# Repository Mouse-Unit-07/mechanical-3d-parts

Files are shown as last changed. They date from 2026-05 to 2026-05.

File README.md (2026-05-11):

# Mechanical 3D Parts

- Mechanical documentation and references for 3D printed parts on the micromouse
- Mechanical calculations and part selections are too closely related to electrical hardware design- this repo will include just 3D modeling related notes
- Includes:
  - Reference links to 3D modeling guides
  - Notes for 3D modeled parts
  - 3D model files for motherboard mounts, wheels, etc

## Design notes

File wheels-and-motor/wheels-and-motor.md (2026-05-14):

# Wheels and Motor Design Explanation

- Notes regarding wheels and related design choices

## Index

- [4 Wheel Drive](#4-wheel-drive)
- [Gears](#gears)
- [Wheel Bearing Spacers](#wheel-bearing-spacers)- [Mechanical Micromouse Specs](#mechanical-micromouse-specs)

## 4 Wheel Drive

- Decimus 4
  - https://micromouseonline.com/2012/05/16/shapeways-motor-mounts-arrive/
  - https://micromouseonline.com/2012/05/24/printed-wheels-complete-decimus-mechanicals/
  - The key is to use ball bearings, spacers, and a screw for a shaft for the wheels to rotate
  - M3 screws and 3mm diameter ball bearings are used for Mouse Unit 07
- Designing gears
  - The key is to design wheels w/ gears on them
  - More details in mechanical design guide

## Gears

- Fusion 360 guide to making gears: https://www.youtube.com/watch?v=B8A_11o7QZ0
- To minimize friction, below settings were used w/ the spur gear generation tool:

```
given 32mm wheels, and target gear ratio of 13:44 pinion to wheel gear:

wheel gear:
- teeth: 44
- module: 0.65
- pressure angle: 20 degrees
- backlash: 0.15
- root fillet radius: 0.38mm
- gear thickness: 3mm
- calculated pitch diameter of 28.6mm (0.65 * 44 = 28.6mm)
- calculated outer diameter of 0.65(44 + 2) = 29.9mm

pinion:
- teeth: 13
- module: 0.65
- pressure angle: 20 degrees
- backlash: 0.15
- root fillet radius: 0.38mm
- gear thickness: 3mm
- calculated pitch diameter of 28.6mm (0.65 * 13 = 8.5mm)
- calculated outer diameter of 0.65(13 + 2) = 9.75mm

```

- Gear train orientation
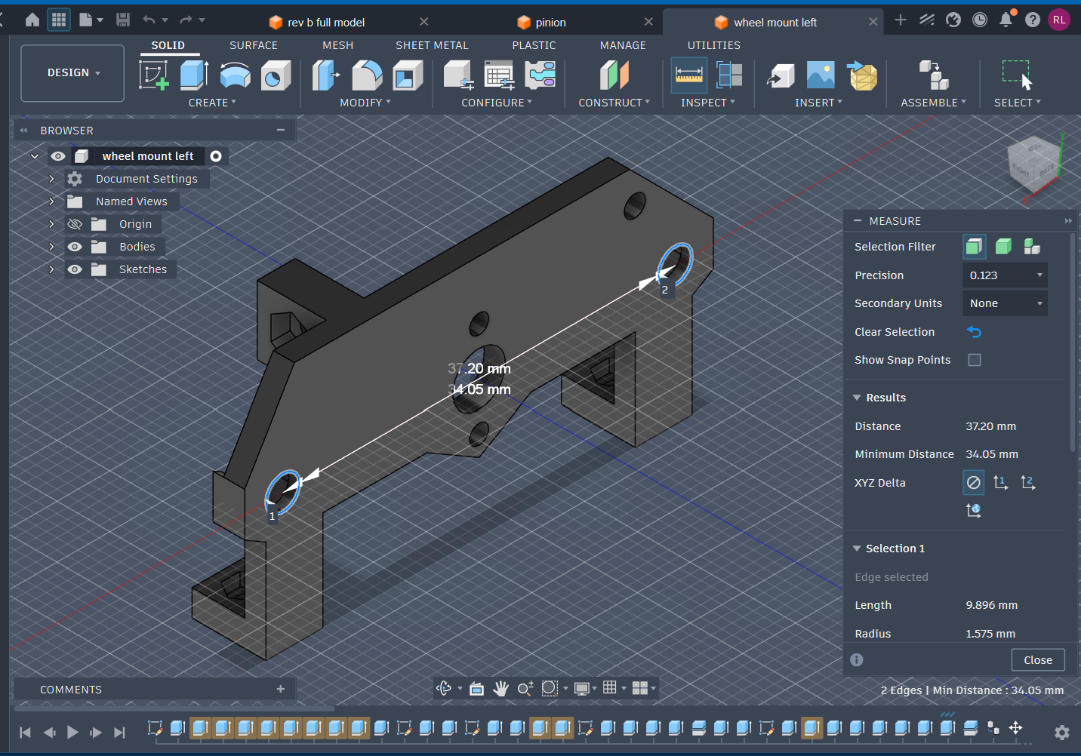
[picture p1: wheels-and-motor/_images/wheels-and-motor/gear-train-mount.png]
gear-train-mount
  - 
  - The pinion gear was originally raised above the wheel gears to reduce wheel to wheel distance, but keeping the pinion at the same height as the wheel gears helps reduce friction
  - Given module of 0.65, 44 teeth on the wheel gear, and 13 teeth on the pinion, the distance from pinion to wheel gear is at minimum:
    - 0.65(13 + 44) / 2 = 18.525
  - To reduce friction, a distance of 18.6mm is used

## Wheel Bearing Spacers

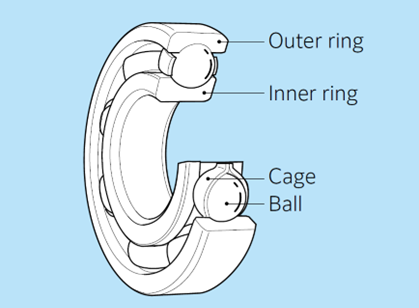
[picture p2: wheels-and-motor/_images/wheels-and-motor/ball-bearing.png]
ball-bearing
- 
- Needed to prevent outer ring of ball-bearings from touching 3D printed mounts and screw heads
- Crucial that they're made of metal- tried to 3D print spacers, but they eventually mold into the shapes of the parts they're spaced between

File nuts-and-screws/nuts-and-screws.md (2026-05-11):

# Nuts and Screws

- Notes regarding nuts and screws

## Index

- [Sockets for Nuts](#sockets-for-nuts)

## Sockets for Nuts

- Sockets for 3D printed parts
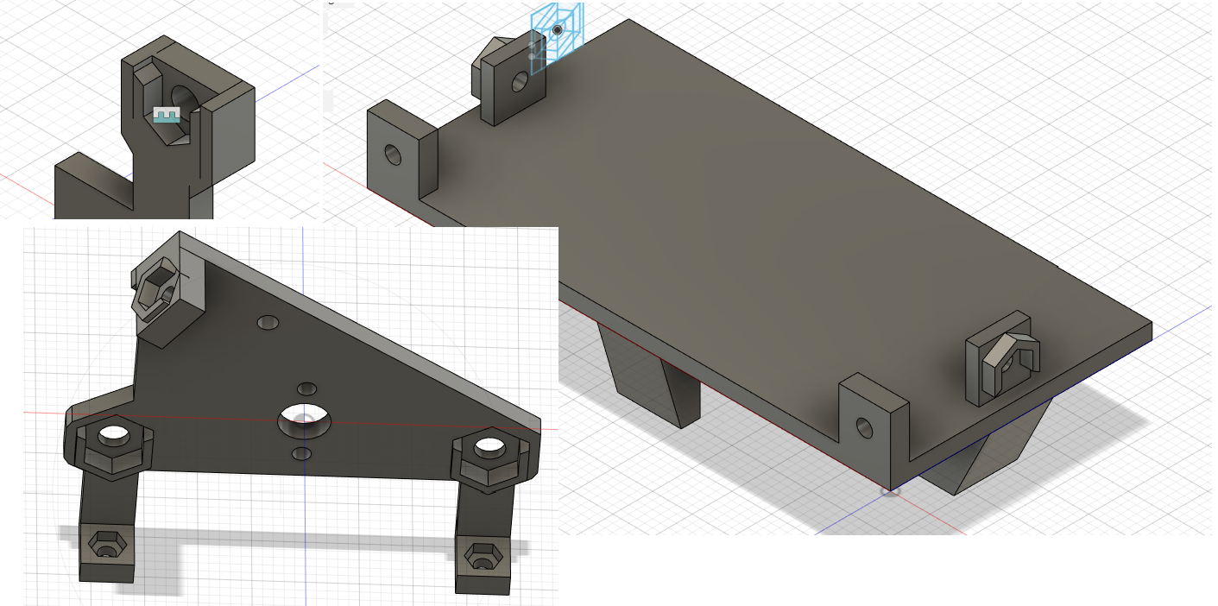
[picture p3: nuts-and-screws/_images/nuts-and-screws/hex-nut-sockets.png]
hex-nut-sockets
  - 
  - It's a major pain when there are nuts and screws that move around in the bot both when assembling and disassembling
  - Add sockets for nuts and superglue them into 3D mounts

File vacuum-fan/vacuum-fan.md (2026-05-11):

# Vacuum Design Explanation

- Notes regarding mechanical vacuum design choices

## Index

- [Impeller Fan Design](#impeller-fan-design)

## Impeller Fan Design

- Lack of documentation
  - Very involved- wish we had a mechanical engineer on the team
  - For whatever reason, there's no documentation regarding micromouse vacuum fan designs
  - ...Except for this: https://rt-net.jp/mobility/archives/20915
    - ^implements a turbo impeller fan <3
- Different impeller fan types compared
  - Video here: https://www.youtube.com/watch?v=mafjVYfFgg4
  - Turbo fan provides the most suction
- Impeller fans
  - there is documentation on impeller fans in general
    - impeller blower configuration video: https://youtu.be/YuEaP9kyiFc?si=spyc_kHSI9guTJmH
    - impeller fan crafted by hand video: https://youtu.be/Hyz1TMbNVSo?si=MinbotT-jVyszSr6
  - puller configuration
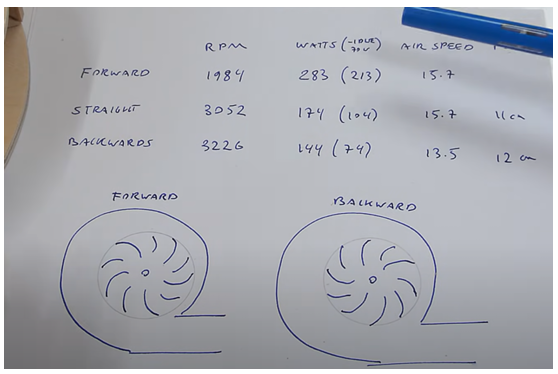
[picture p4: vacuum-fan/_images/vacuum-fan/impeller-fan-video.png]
impeller-fan-video
    - 
      - when a fan's wings scoop the air, it's pusher configuration
      - when a fan's wings swing air out, it's puller configuration
      - in the above image, when the fan moves counter-clockwise it's the most efficient design in terms of power consumption and RPM
- Failed designs
  - ball-bearing
  - Reasons for failure include lack of suction, lack of durability (fan parts break apart), and noise
    - Second to last failing design is intolerably loud
    - Last design is essentially the working design, but a bit too tall and wide
- Green Ye
  - http://greenye.net/Pages/Micromouse/Micromouse2016-2017.htm
  - Allocates 3cm to vacuum on PCB, and 1.5cm for the hole for suction
  - Mouse Unit 07 arbitrarily does the same
- Excel-9a
  - Video: https://www.youtube.com/watch?v=1_KpQ1bw5I8
  - Documentation: https://sites.google.com/site/myprojectq/robotic/classic-micromouse/excel-9a?pli=1
  - The mouse that defies gravity
- Micromouse online
  - https://micromouseonline.com/2018/02/18/more-suck-less-slip/
  - Yes, vacuum means less slip indeed

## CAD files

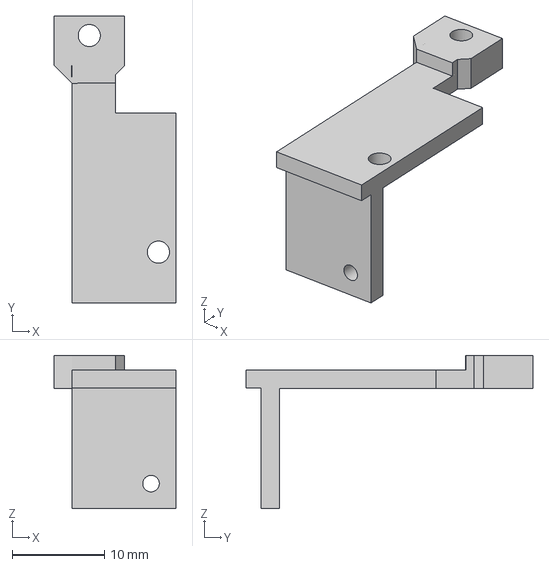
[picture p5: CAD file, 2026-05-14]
model-files/sharp sensor mount.3mf
13.2 x 31.1 x 16.6 mm

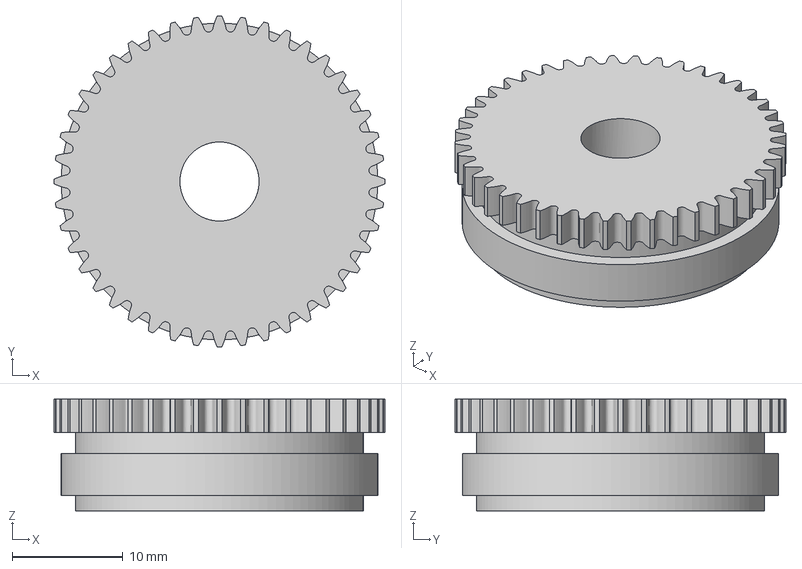
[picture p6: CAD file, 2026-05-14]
model-files/wheel gear.3mf
29.9 x 29.9 x 10.1 mm

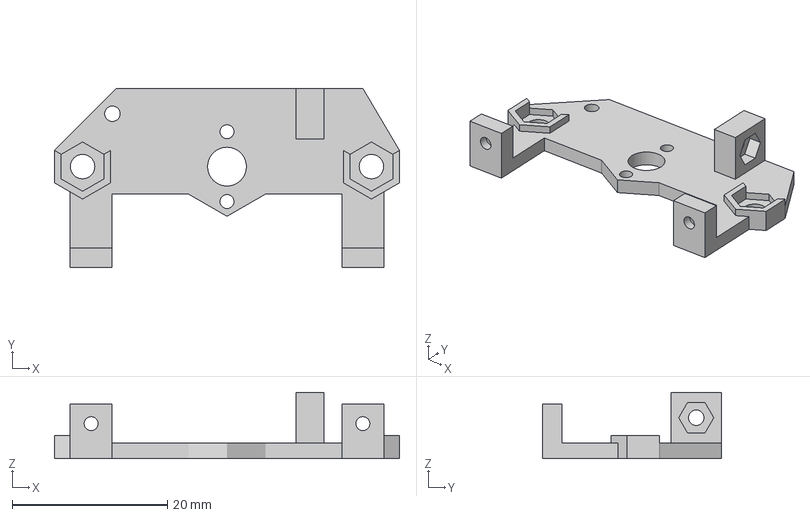
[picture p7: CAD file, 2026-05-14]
model-files/wheel mount left.3mf
44.4 x 23.1 x 8.52 mm

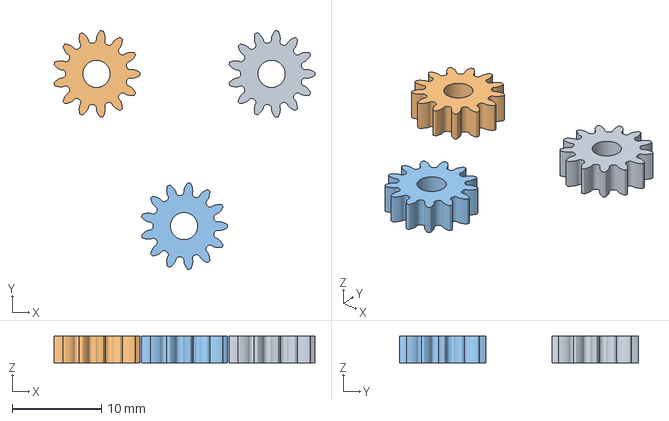
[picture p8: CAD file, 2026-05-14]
model-files/pinion.3mf
29.3 x 26.8 x 3.00 mm
Spur Gear (13 teeth) x 3

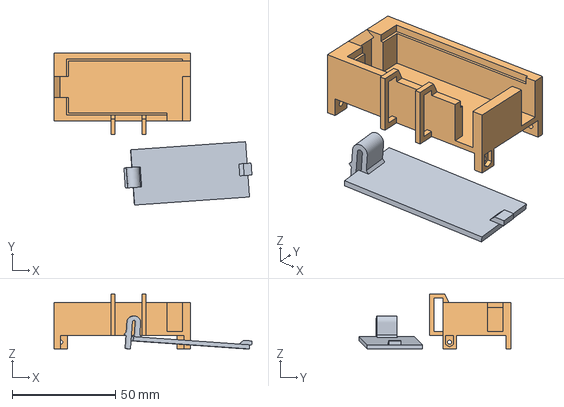
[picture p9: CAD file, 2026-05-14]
model-files/Battery Mount Lid.3mf
95.7 x 73.6 x 26.5 mm

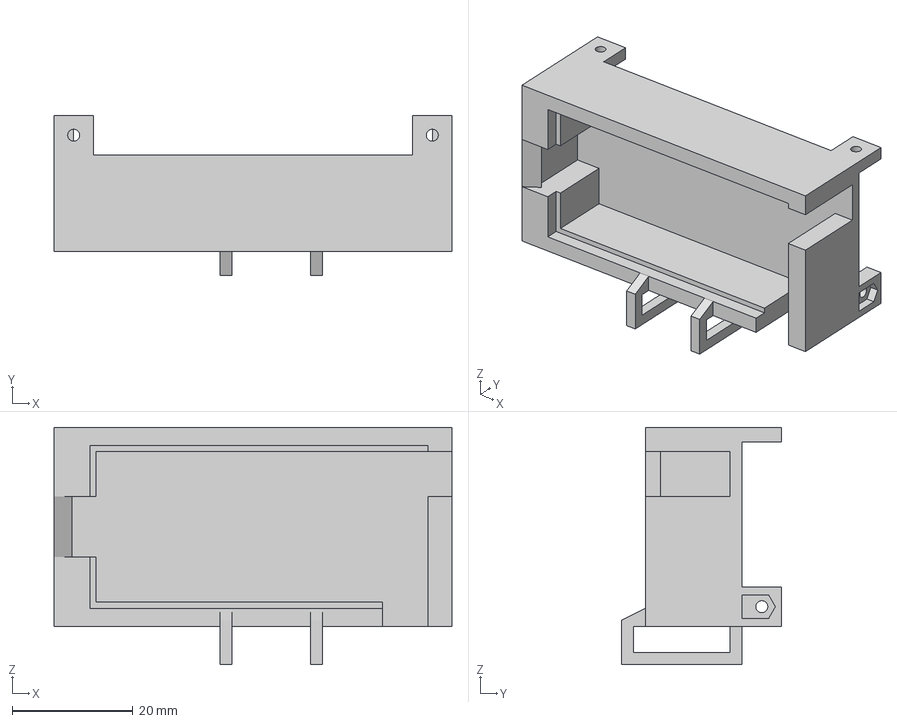
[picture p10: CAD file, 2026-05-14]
model-files/Battery Mount- 450mAh LiPo.3mf
66.0 x 26.5 x 39.4 mm

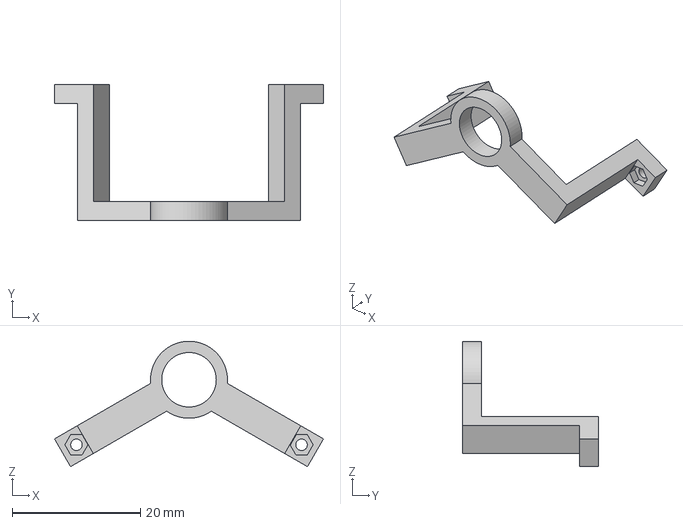
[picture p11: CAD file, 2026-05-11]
model-files/vacuum motor mount.3mf
41.9 x 21.2 x 19.5 mm

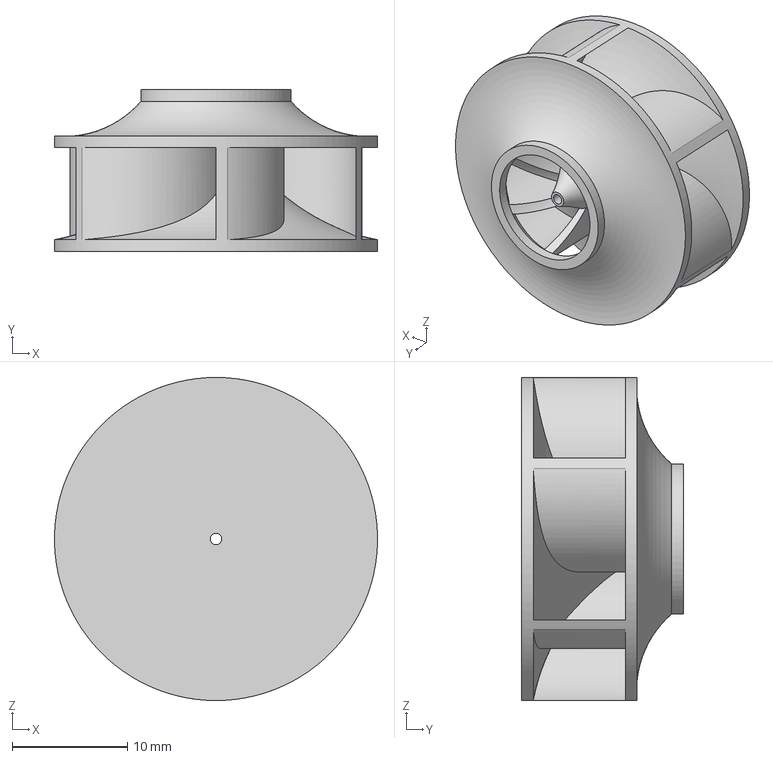
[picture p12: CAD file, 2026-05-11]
model-files/vacuum fan.3mf
28.0 x 14.0 x 28.0 mm

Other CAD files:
model-files/wheel mount right.3mf

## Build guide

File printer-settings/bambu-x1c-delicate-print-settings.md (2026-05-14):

# Bambu X1 Carbon Printer Settings

- Below are Bambu Studio printer settings for delicate prints like gears
- Printing the gears one by one is necessary for avoiding scars and imperfections from the printer moving around to print multiple items 

## Index

- [Quality](#quality)
- [Strength](#strength)
- [Speed](#speed)
- [Support](#support)
- [Others](#others)

## Quality

- layer height
  - layer height: 0.08mm
  - initial layer height: 0.2mm
  - mixed color sublayer: disabled
- line width
  - default: 0.42mm
  - initial layer: 0.5mm
  - outer wall: 0.4mm
  - inner wall: 0.45mm
  - top surface: 0.42mm
  - sparse infill: 0.45mm
  - internal solid infill: 0.42mm
  - support: 0.42mm
- seam
  - seam position: aligned
  - seam placement away from overhangs (experimental): disabled
  - smart scarf seam application: disabled
  - scarf application angle threshold: 155
  - scarf around entire wall: disabled
  - scarf steps: 10
  - scarf join for inner walls: enabled
  - override filament scarf seam setting: disabled
  - role-based wipe speed: enabled
- precision
  - slice gap closing radius: 0.049mm
  - resolution: 0.012mm
  - arc fitting: enabled
  - X-Y hole compensation: 0.03mm
  - X-Y contour compensation: -0.02mm
  - auto circle contour-hole compensation: disabled
  - elephant foot compensation: 0.15mm
  - precise Z height: disabled
- ironing
  - ironing type: no ironing
- wall generator
  - wall generator: classic
- advanced
  - order of walls: outer/inner
  - print infill first: disabled
  - bridge flow: 1
  - thick bridges: disabled
  - only one wall on top surfaces: top surfaces
  - only one wall on first layer: disabled
  - smooth speed discontinuity area: enabled
  - smooth coefficient: 150
  - avoid crossing wall: enabled
  - avoid crossing wall - max detour length: 100%
  - avoid crossing wall - includes support: disabled
  - smoothing wall speed along Z (experimental): disabled

## Strength

- walls
  - wall loops: 4
  - embedding the wall into the infill: disabled
  - detect thin wall: disabled
- top/bottom shells
  - top surface pattern: monotonic line
  - top surface density: 100%
  - top shell layers: 9
  - top shell thickness: 0.8mm
  - top paint penetration layers: 9
  - bottom surface pattern: monotonic
  - bottom surface density: 100%
  - bottom shell layers: 7
  - bottom shell thickness: 0mm
  - bottom paint penetration layers: 7
  - internal solid infill pattern: rectilinear
- sparse infill:
  - sparse infill density: 100%
  - fill multiline: 1
  - sparse infill pattern: rectilinear
  - length of sparse infill anchor: 400%
  - maximum length of sparse infill anchor: 20mm
- advanced:
  - infill/wall overlap: 15%
  - infill direction: 45 degrees
  - bridge direction: 0 degrees
  - minimum sparse infill threshold: 15mm^2
  - infill combination: disabled
  - detect narrow internal solid infill: enabled
  - ensure vertical shell thickness: enabled
  - detect floating vertical shells: enabled

## Speed

- initial layer speed:
  - initial layer: 20mm/s
  - initial layer infill: 105mm/s
- other layers speed:
  - outer wall: 30mm/s
  - inner wall: 70mm/s
  - small perimeters: 50%
  - small perimeter threshold: 0mm
  - sparse infill: 450mm/s
  - internal solid infill: 350mm/s
  - vertical shell speed: 80%
  - top surface: 200mm/s
  - slow down for overhangs: enabled
  - overhang speed:
    - 60mm/s: 10%
    - 30mm/s: 25%
    - 10mm/s: 50%
    - 10mm/s: 75%
    - 10mm/s: 100%
  - slow down by height: disabled
  - bridge: 50mm/s
  - gap infill: 350mm/s
  - support: 150mm/s
  - support interface: 80mm/s
- travel speed:
  - travel: 500mm/s
- acceleration:
  - normal printing: 10000mm/s^2
  - travel: 4000mm/s^2
  - initial layer travel: 6000mm/s^2
  - initial layer: 500mm/s^2
  - outer wall: 1200mm/s^2
  - inner wall: 0mm/s^2
  - top surface: 2000mm/s^2
  - sparse infill: 100%

## Support

- support
  - enable support: enabled
  - type: tree(auto)
  - style: default
  - threshold angle: 15
  - on build plate only: disabled
  - support critical regions only: disabled
  - remove small overhangs: enabled
- raft:
  - raft layers: 0
- filament supports:
  - support/raft base: default
  - support/raft interface: default
- advanced:
  - initial layer density: 90%
  - initial layer expansion: -1mm
  - support wall loops: -1
  - top z distance: 0.08mm
  - bottom z distance: 0.08mm
  - base pattern: default
  - base pattern spacing: 2.5mm
  - pattern angle: 0 degrees
  - top interface layers: 2 layers
  - interface pattern: default
  - top interface spacing: 0.5mm
  - normal support expansion: 0mm
  - support/object xy distance: 0.35mm
  - z overrides x/y: disabled
  - support/object first layer gap: 0.2mm
  - max bridge length: 0mm
  - independent support layer height: enabled
- tree support:
  - branch distance: 5mm
  - branch diameter: 2mm
  - branch angle: 45 degrees
  - branch diameter angle: 5 degrees

## Others

- bed adhesion:
  - skirt loops: 0
  - skirt height: 1
  - brim type: auto
  - brim width: 5mm
  - brim-object gap: 0.1mm
- prime tower:
  - enable: enabled
  - skip points: enabled
  - internal ribs: disabled
  - width: 35mm
  - max speed: 90mm/s
  - brim width: 3mm
  - infill gap: 150%
  - rib wall: enabled
  - extra rib length: 0mm
  - rib width: 8mm
  - fillet wall: enabled
- purge options:
  - purge into objects' infill: disabled
  - purge into objects' support: enabled
- special mode:
  - slicing mode: regular
  - print sequence: by layer
  - spiral vase: disabled
  - timelapse: traditional
  - fuzzy skin: none
  - fuzzy skin generator mode: displacement
  - fuzzy skin noise type: classic
  - fuzzy skin point distance: 0.3mm
  - fuzzy skin thickness: 0.2mm
  - apply fuzzy skin to first layer: disabled
- advanced:
  - use beam interlocking: disabled
  - interlocking depth of a segmented region: 0mm
- g-code output:
  - reduce infill retraction: auto

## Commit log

2026-05-11 docs: add documentation and files from team guides and hardware motherboard repos
    [Battery Mount- 450mAh LiPo.3mf, sharp sensor mount.3mf, vacuum fan.3mf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]
2026-05-14 docs: update 3d model files and wheel/gear train documentation, add printer settings documentation
    [Battery Mount Lid.3mf, Battery Mount- 450mAh LiPo.3mf, pinion.3mf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]
